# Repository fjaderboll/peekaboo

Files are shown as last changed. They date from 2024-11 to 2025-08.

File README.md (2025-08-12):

# Peek-a-boo
A mobile robot that like to play hide-n-seek with you or just
follow you around.

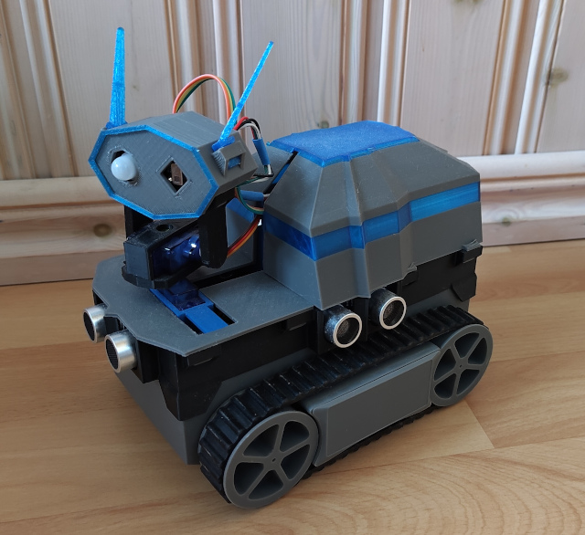
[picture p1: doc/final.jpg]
final Final


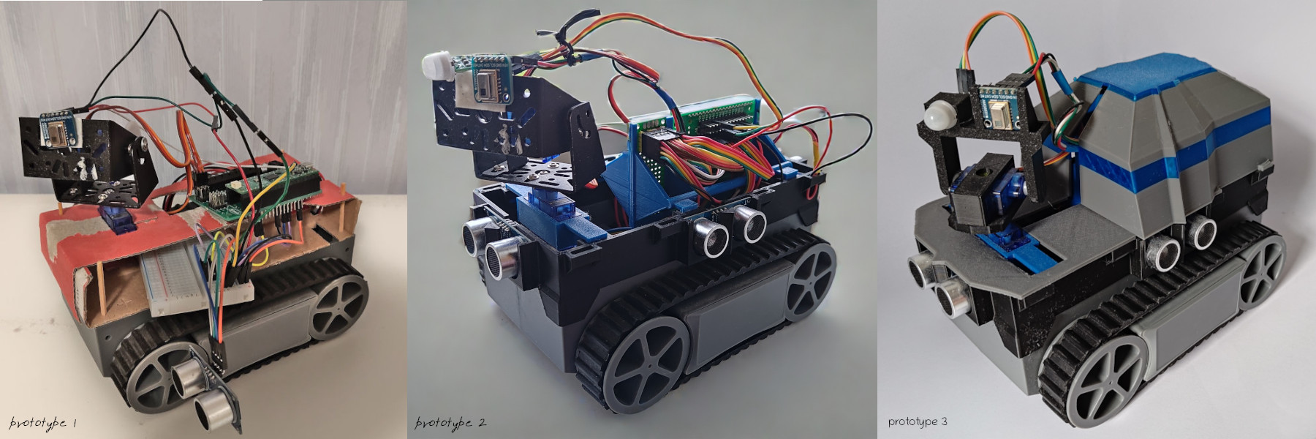
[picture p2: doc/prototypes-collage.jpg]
prototypes Prototypes


More technically, it will use a heat camera to detect humans
and ultrasonic sensors for navigating a flat surface with obstacles.
If left unattended it will go to asleep and awoken by movement.

Watch it in action on [YouTube](https://www.youtube.com/watch?v=vqpeKBAsQWM).

## Hardware parts
* Crawler: wheel base with motors and battery pack
* Microcontroller: [Raspberry Pi Pico H](https://www.raspberrypi.com/documentation/microcontrollers/pico-series.html#pico-1-family) ([pinout](https://www.raspberrypi.com/documentation/microcontrollers/images/pico-pinout.svg))
* Heat camera: AMG8833 ([library](https://github.com/peterhinch/micropython-amg88xx))
* Motor/servo shield: [Kitronik Robotics Board](https://github.com/KitronikLtd/Kitronik-Pico-Robotics-Board-MicroPython) ([pinout](https://kitronik.co.uk/cdn/shop/products/5329_additional-1-kitronik-robotics-board-for-raspberry-pi-pico_800x.jpg))
* Servo motors: 2 x SG90
* Movement detection: PIR [SR505](https://hobbycomponents.com/sensors/1066-sr505-miniature-pir-sensor-module) **\***
* Ultrasonic sensors: 4 x HC-SR04
* Sound: Passive piezo buzzer
* Power switch: Toggle switch
* Body parts: [see more here](body-parts/README.md)

**\*** SR505 needs 5-12V to behave correctly, and the Robotics Board supply only 3.3V for peripherals, so *VIN* connected directly to the battery PIN.

## Software
I use *Thonny* for installing MicroPython and for coding *Visual Studio Code* with extension `MicroPico`.

Either way, upload content in folder `app` into root of the microcontroller. (VSCode command `MicroPico: Upload project to Pico`)

## Limitations and room for improvements
The head will focus on the warmest thing in view, which works pretty well.
However, the "human detection" is very simplistic; if the center of the heat
camera's image has an average temperature above 25 degrees it's a hit.
It's not much you can do with a 8x8 pixel image, but some form of shape
recognition should be possible.

Navigation is pretty much drive forward-ish (where the head points) until too
close to something, then turn away from obstacle, repeat.
The ultrasonic sensors may be good at determine the distance, but it's hard to
tell the angle to the obstacle. And with only four of them, it leaves several
dead angles. Though, some form of obstacle heat map or SLAM might still be
possible.

Also, a bump sensor of some sort would be a plus; the ultrasonic sensor is
equally bad vertically, so too low or semi-high obstacles may not be seen and
it will endlessly try to continue driving.

## Abandoned paths
I've been intrigued to use AI, and the Pico should be strong enough handle small models.
However, TensorFlow Lite in conjuction with MicroPython posed a too great challenge at the moment.

Also considered using *Pico 2 W* and connect a Bluetooth gamepad for manual driving,
which would have come handy in generating training data for a model. However,
at the moment native Bluetooth support is very limited.

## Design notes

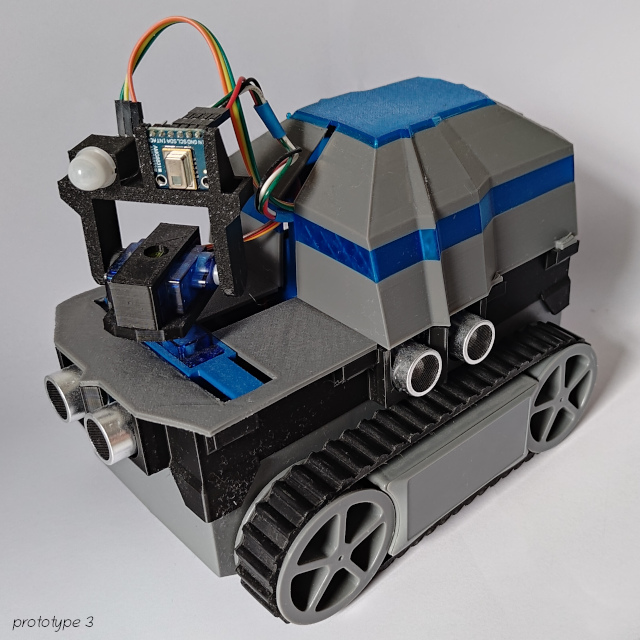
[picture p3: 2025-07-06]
doc/prototype3.jpg

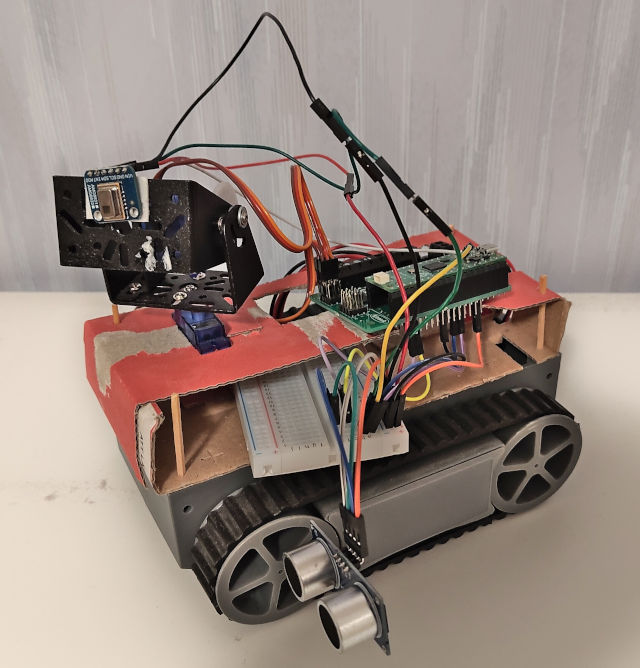
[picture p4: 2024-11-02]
doc/prototype1.jpg

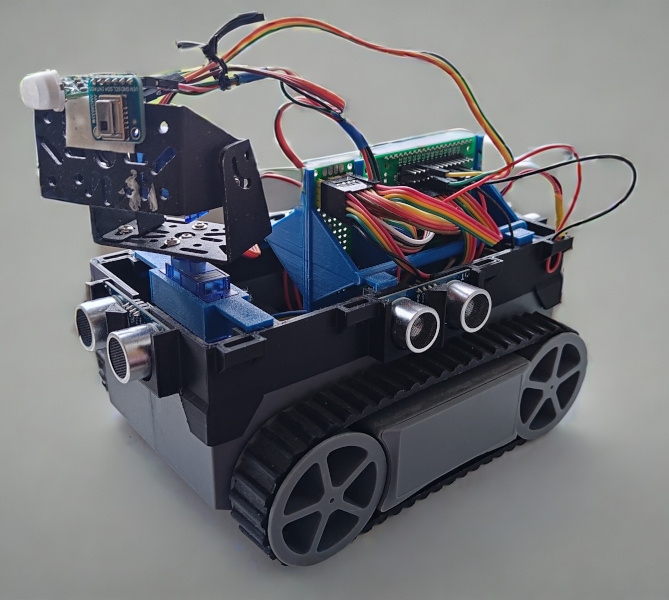
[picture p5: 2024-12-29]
doc/prototype2.jpg

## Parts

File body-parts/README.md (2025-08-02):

# Body parts - 3D-printable
These models are made using OpenSCAD.

## Base / inside

* **Grey** base frame (`base.scad`)
* **Red/blue** snap-on to crawler (`base_clip.scad`)
* **Aqua** ultrasonic holders (`ultrasonic-holder.scad`)
* **Yellow** addon holders (`addon_support.scad`)
* **Orange** addons for servo motor and PCBs (`addon_servo.scad`, `addon_shield.scad`)
* **Green** PCBs just for illustration (`pcb.scad`)

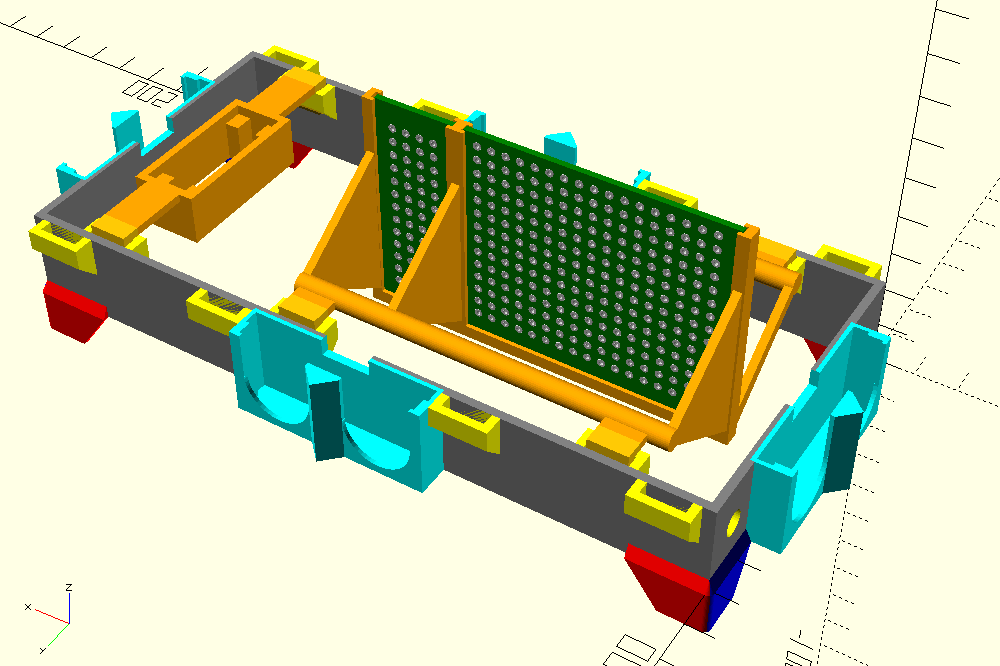
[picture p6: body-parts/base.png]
base Base


## Head
Servo-tilt with sockets for the heat camera and the PIR sensor.
Also addon holders for exterior case.

* **Yellow/blue** tilt/pitch frame with heat camera and PIR mount (`head_tilt.scad`)
* **Orange/pink** base/yaw holder for frame (`head_base.scad`)

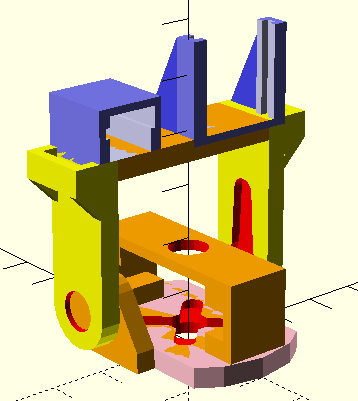
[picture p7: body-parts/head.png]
head Head


## Chassi / outside
Will go into the outer addon holders.

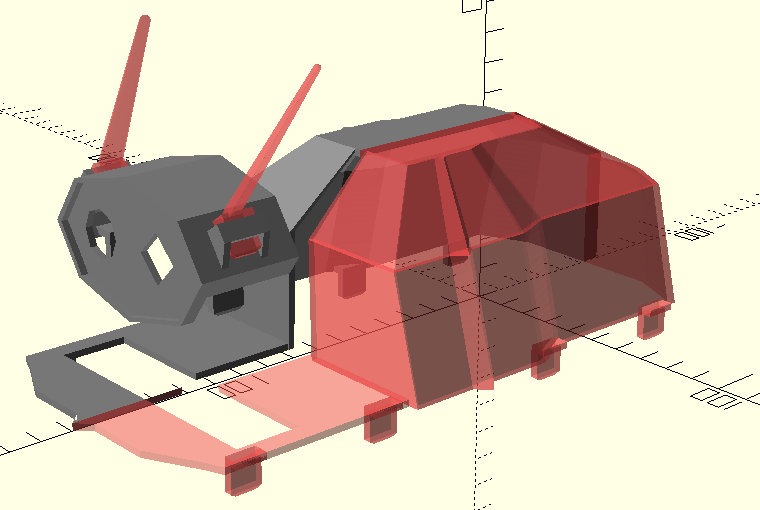
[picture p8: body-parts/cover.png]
cover Cover


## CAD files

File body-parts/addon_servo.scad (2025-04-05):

use <addon_support.scad>

bw = 80;  // base width
wt = 2;   // wall thickness

sw = 12;  // servo width
sl = 23;  // servo length

hl = 32.8; // servo holder length
ht = 2.5;  // servo holder thickness
cw = 4.8;  // cord width
co = 10;   // cord offset from holder

m = 0.20; // margin

module servo_box() {
    color("orange") translate([0, 0, -(ht+co)/2]) cube([sw+2*m+2*wt, hl+2*m+2*wt, ht+co], center=true);
}

module servo_holder() {
    difference() {
        servo_box();
    
        color("orange")  {
            // top hole for holder
            translate([0, 0, 0]) cube([sw+2*m, hl+2*m, 2*ht], center=true);
            // bottom hole for body
            translate([0, 0, -co]) cube([sw+2*m, sl+2*m, 2*co], center=true);
            // cord hole
            translate([0, 0, -co]) cube([cw+2*m, hl+2*m, 2*co], center=true);
        }
    }
}

module addon_servo() {
    w = bw-2*wt;
    
    difference() {
        translate([0, -w/2, -wt]) addon_bar(w);
        translate([0, 0, 0.1]) servo_box();
    }
    servo_holder();
}

addon_servo();

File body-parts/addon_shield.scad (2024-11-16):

bw = 80;   // base width
wt = 2;    // wall thickness

m = 0.30;  // margin
pt = 1.5;  // PCB thickness
ht = 1.0;  // holder thickness

sw = 64.4; // shield width
sh = 53.5; // shield height
aw = 20;   // addon card width
ah = 80;   // addon card height

use <addon_support.scad>

module addon_shield() {
    w = bw-2*wt;
    
    module clips_oneside() {
        translate([0, -w/2, -wt]) addon_bar(width=15, single_clip=true);
        translate([75, -w/2, -wt]) addon_bar(width=15, single_clip=true);
        color("orange") translate([-9.5, -w/2+10, 1-wt]) rotate(90, [0, 1, 0], $fn=40) cylinder(h=90.5, d=5);
    }
    module clips() {
        clips_oneside();
        mirror([0, 1, 0]) clips_oneside();
    }
    module cards_holder() {
        tw = wt+sw+wt+aw+wt+4*m;
        tt = ht+pt+ht+2*m;
        th = wt+sh+m;
        
        difference() {
            // full size
            translate([0, -tt/2, 0]) cube([tw, tt, th]);
            // shield hole
            x1=wt;
            translate([x1, -(pt+2*m)/2, wt]) cube([sw+2*m, pt+2*m, th]);
            // see-through shield hole
            translate([x1+ht, -tt, wt+ht]) cube([sw+2*m-2*ht, 2*tt, th]);
            translate([x1+ht+2, -(pt+m)/2-tt, -wt]) cube([sw+2*m-2*ht-5-3, tt, th]);
            
            // addon card hole
            x2=x1+wt+sw+3*m;
            translate([x2, -(pt+2*m)/2, wt]) cube([aw+2*m, pt+2*m, th]);
            // see-through addon card hole
            translate([x2+ht, -tt, wt+ht]) cube([aw+2*m-2*ht, 2*tt, th]);
        }
    }
    module foot() {
        s=26;
        translate([0, -28, -1])
        rotate(90, [0, 0, 1])
        rotate(90, [1, 0, 0])
        linear_extrude(height=wt)
        polygon([
            [0, 2.5],
            [s, -17.5],
            [s, -22.5],
            [0, -1]
        ]);
    }
    module triangle() {
        s=29;
        translate([0, -30.5, -1])
        rotate(90, [0, 0, 1])
        rotate(90, [1, 0, 0])
        linear_extrude(height=wt)
        polygon([
            [0, 0],
            [s, s/1.5],
            [s, -s/1.5]
        ]);
    }
    /*module triangle_light() {
        difference() {
            triangle();
            translate([-0.1, 0, 0]) scale([1.1, 0.7, 0.7]) triangle();
        }
    }*/
    module cards_holder_holder() {
        translate([-9.5, 0, 0]) foot();
        translate([57, 0, 0]) triangle();
        translate([79, 0, 0]) triangle();
        
        translate([-9.5, 0, 0]) mirror([0, 1, 0]) triangle();
        translate([57, 0, 0]) mirror([0, 1, 0]) triangle();
        translate([79, 0, 0]) mirror([0, 1, 0]) triangle();
    }
    
    clips();
    color("orange") translate([-10, 0, -22-wt]) cards_holder();
    color("orange") cards_holder_holder();
}

addon_shield();

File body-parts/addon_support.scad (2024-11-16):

iw = 10;  // inner width
it = 3;   // inner thickness
h = 5;    // height
wt = 2;   // wall thickness
m = 0.30; // margin

module addon_holder() {
    module reinforcement() {
        rotate(90, [0, 0, 1])
        rotate(90, [1, 0, 0])
        linear_extrude(height=wt)
        polygon([
            [0, 0],
            [it+wt, 0],
            [0, -h]
        ]);
    }
    
    color("yellow") translate([-wt-iw/2, 0, -h]) {
        difference() {
            cube([iw+2*wt, it+wt, h]);
            translate([wt, -1, -1]) cube([iw, it+1, h+2]);
        }
        reinforcement();
        translate([iw+wt, 0, 0]) reinforcement();
    }
}

module addon_clip(bar_length=0) {
    ch = 1.5*h;
    
    color("#fcc705") {
        translate([-(iw-2*m)/2, m, -ch])
        cube([iw-2*m, it-2*m, ch]);
        
        translate([-(iw-2*m)/2, m, 0])
        cube([iw-2*m, it+wt-m, wt]);
    
        translate([0, (it-2*m)/2+m, -ch-1])
        resize([iw-2*m, it-2*m, 1])
        rotate(45, [0, 0, 1])
        cylinder(h=1, r1=it/3, r2=it/2, $fn=4);
    }
}

module addon_bar(width, single_clip=false) {
    addon_clip();
    if(!single_clip) {
        translate([0, width, 0]) mirror([0, 1, 0]) addon_clip();
    }
    
    color("orange")
    translate([-(iw-2*m)/2, it+wt, 0])
    cube([iw-2*m, width-2*(it+wt), wt]);
}

addon_holder();
//addon_bar(width=15, single_clip=true);
addon_bar(width=20);

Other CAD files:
body-parts/base.scad
body-parts/addon_bar_test.scad
body-parts/base_clip.scad
body-parts/cover_back.scad
body-parts/cover_front.scad
body-parts/head_antenna.scad
body-parts/head_base.scad
body-parts/head_face.scad
body-parts/head_tilt.scad
body-parts/mount_heat_camera.scad
body-parts/mount_pir.scad
body-parts/pcb.scad
body-parts/ultrasonic-holder.scad

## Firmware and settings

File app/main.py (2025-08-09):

import gc
import utime
from machine import Pin, SoftI2C

import PicoRobotics
from buzzer import Buzzer
from buzzer_sounds import Sounds
from ultrasonic import Ultrasonic

from head import Head
from body import Body

print('Starting...')

# === init variables ===
pirPin = Pin(19, Pin.IN)
ledPin = Pin("LED", Pin.OUT)

board = PicoRobotics.KitronikPicoRobotics() # uses i2c1
buzzer = Buzzer(18)
sounds = Sounds(buzzer)
i2c0 = SoftI2C(scl=Pin(17), sda=Pin(16), freq=100_000)
utime.sleep(1)

sensor_front = Ultrasonic(11, 15, 'Front')
sensor_left  = Ultrasonic(10, 14, 'Left')
sensor_right = Ultrasonic(7, 13, 'Right')
sensor_back  = Ultrasonic(6, 12, 'Back')

head = Head(board, i2c0, servo_yaw=7, servo_pitch=8)
body = Body(board, head, sensor_front, sensor_left, sensor_right, sensor_back)

# === end init variables ===

def mem():
  gc.collect()
  free = gc.mem_free()
  alloc = gc.mem_alloc()
  total = free + alloc
  print(f'Memory used: {alloc/total*100:.1f}%')

def pir_irq(pin):
    global sleep_mode

    if pin.value():
        print('PIR detected motion')
        sleep_mode = False
    else:
        print('PIR motion stopped')
    
    ledPin.value(pin.value())

def start():
    global sleep_mode

    print('Started')
    sounds.play_startup()

    start_time = utime.ticks_ms()
    start_hold = True
    last_found_time = start_time
    last_found_someone = False
    last_print_time = 0
    sleep_mode = False

    while True:
        # stay still initially
        if start_hold:
            start_hold = (utime.ticks_diff(utime.ticks_ms(), start_time) < 7000)
            if not start_hold:
                sounds.play_startup_end()

        # move stuff
        head.update()
        body.update(start_hold)

        # did we find someone?
        if head.has_found_someone():
            if not last_found_someone:
                print('Found someone')
                sounds.play_found_someone()
                last_found_someone = True
                last_found_time = utime.ticks_ms()
        else:
            if last_found_someone:
                print('Lost someone')
                sounds.play_lost_someone()
                last_found_someone = False
            
            # go to sleep after if no one found in a while
            if utime.ticks_diff(utime.ticks_ms(), last_found_time) > 60000:
                print('Entering sleep mode')
                body.stop_motors()
                head.sleep_position()
                sleep_mode = True
                sounds.play_sleep()
                break

        # debug print state
        if utime.ticks_diff(utime.ticks_ms(), last_print_time) > 1000:
            #head.print_state(print_camera=False)
            body.print_state()
            last_print_time = utime.ticks_ms()
        
        # idle a little
        utime.sleep_ms(10)

# === main ===
sleep_mode = False
pirPin.irq(trigger=Pin.IRQ_RISING | Pin.IRQ_FALLING, handler=pir_irq)

try:
    while True:
        if not sleep_mode:
            start()
        utime.sleep_ms(500)
except KeyboardInterrupt:
    print('KeyboardInterrupt')
finally:
    print('Shutting down')
    body.stop_motors()
    buzzer.silent()

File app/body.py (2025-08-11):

import utime

from PicoRobotics import KitronikPicoRobotics
from ultrasonic import Ultrasonic
from head import Head

class Body:
    DIRECTION_FORWARD: str = 'r'  # switched reverse and forward to match reality
    DIRECTION_BACKWARD: str = 'f'
    MOTOR_LEFT: int = 1
    MOTOR_RIGHT: int = 2
    SPEED_MIN: int = 25  # below this the motor doesn't move
    SPEED_MAX: int = 100

    def __init__(self, board: KitronikPicoRobotics, head: Head, sensor_front: Ultrasonic, sensor_left: Ultrasonic, sensor_right: Ultrasonic, sensor_back: Ultrasonic):
        self.board = board
        self.head = head
        self.sensor_front = sensor_front
        self.sensor_left  = sensor_left
        self.sensor_right = sensor_right
        self.sensor_back  = sensor_back
        
        self.sensors = [sensor_front, sensor_left, sensor_right, sensor_back]
        self.proximity_threshold = 5
        self.sensor_update_interval = 250
        self.last_update_time = 0

        self.angle = 0        # range: -180 to +180
        self.speed = 0        # range:    0 to +100
        self.last_speed = -1
        self.last_angle = -1
        self.speed_slowdown = 100

        self.mode_text = 'init'

    def get_distances(self):
        return [sensor.get_last_distance() for sensor in self.sensors]

    def print_state(self):
        for sensor in self.sensors:
            print(f'l{sensor.get_name()}: {sensor.get_last_distance():.1f} cm', end=' ')
        print(f'speed: {self.speed}, angle: {self.angle}, head_angle: {self.head.get_direction_angle()}, mode: {self.mode_text}')

        #for sensor in self.sensors:
        #    print(f'c{sensor.get_name()}: {sensor.get_calibrated_distance():.1f} cm', end=' ')
        #print()

    def read_sensors(self):
        for i, sensor in enumerate(self.sensors):
            sensor.measure_distance()
    
    def get_safe_speed(self, speed):
        return int(max(self.SPEED_MIN, min(speed, self.SPEED_MAX)))

    def calculate_movement(self, stand_still: bool = False):
        if stand_still:
            self.mode_text = 'stand still'
            self.speed = 0
            self.speed_slowdown = 100
            self.angle = 0
        elif self.head.has_found_someone():
            self.mode_text = 'found someone'
            self.speed = 0
            self.speed_slowdown = 100
            self.angle = self.head.get_direction_angle()
            if abs(self.angle) < 30:
                self.angle = 0
        else:
            distance_front = self.sensor_front.get_calibrated_distance()
            distance_left  = self.sensor_left.get_calibrated_distance()
            distance_right = self.sensor_right.get_calibrated_distance()
            distance_back  = self.sensor_back.get_calibrated_distance()
            head_angle = self.head.get_direction_angle()

            if distance_front < 10 and distance_back > 10: # move backward (at an angle)
                self.mode_text = 'back'
                self.speed = 1 # slowest possible
                self.speed_slowdown = 100
                self.angle = (-150 if distance_left < distance_right else 150)
            elif distance_front < 20: # turn on the spot
                self.mode_text = 'turn'
                self.speed = 0
                self.speed_slowdown = max(50, self.speed_slowdown + 5)
                self.angle = 20 * (1 if head_angle > 0 else -1)
            else: # move forward against the head angle but stay away from obstacles
                self.mode_text = 'forward'
                df = min(1, distance_front / 100)
                dl = min(1, distance_left / 100)
                dr = min(1, distance_right / 100)
                self.speed = self.get_safe_speed(df * 50 + dl * 25 + dr * 25)
                self.speed_slowdown = max(0, self.speed_slowdown - 5)
                self.angle = head_angle * 1.0 - dl * 30 + dr * 30
        
        self.speed = self.speed if self.speed == 0 else self.get_safe_speed(self.speed - self.speed_slowdown)
        self.angle = int(self.angle)

    def update_motors(self):
        if self.last_angle == self.angle and self.last_speed == self.speed:
            return

        if self.speed == 0 and abs(self.angle) <= 10:
            self.stop_motors()
        elif self.speed == 0:
            angle_speed = self.get_safe_speed(abs(self.angle))
            self.board.motorOn(self.MOTOR_LEFT,  self.DIRECTION_BACKWARD if self.angle < 0 else self.DIRECTION_FORWARD, angle_speed)
            self.board.motorOn(self.MOTOR_RIGHT, self.DIRECTION_BACKWARD if self.angle > 0 else self.DIRECTION_FORWARD, angle_speed)
        else:
            direction = self.DIRECTION_FORWARD if abs(self.angle) <= 90 else self.DIRECTION_BACKWARD
            angle_offset_speed = abs(self.angle) if abs(self.angle) <= 90 else 180 - abs(self.angle)
            speed_left = self.get_safe_speed(self.speed - (0 if self.angle >= 0 else angle_offset_speed))
            speed_right = self.get_safe_speed(self.speed - (0 if self.angle <= 0 else angle_offset_speed))

            if speed_left == self.SPEED_MIN and speed_right == self.SPEED_MIN and self.angle not in [0, 180]:
                if self.angle < 0:
                    speed_left = 0
                else:
                    speed_right = 0

            self.board.motorOn(self.MOTOR_LEFT, direction, speed_left)
            self.board.motorOn(self.MOTOR_RIGHT, direction, speed_right)

        self.last_speed = self.speed
        self.last_angle = self.angle
    
    def stop_motors(self):
        self.board.motorOff(self.MOTOR_LEFT)
        self.board.motorOff(self.MOTOR_RIGHT)

    def update(self, stand_still: bool = False):
        if utime.ticks_diff(utime.ticks_ms(), self.last_update_time) > self.sensor_update_interval:
            self.read_sensors()
            self.calculate_movement(stand_still)
            self.update_motors()
            self.last_update_time = utime.ticks_ms()
            return True
        return False
        

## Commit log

2024-10-04 Improved heat rendering
2024-10-04 Motor shield from Kitronik
2024-11-02 Added ultrasonic test
2024-11-03 First draft of the structure to 3D print, using OpenSCAD
    [base.scad, ultrasonic-holder.scad]
2024-11-03 Ultrasonic holder adjustments
    [ultrasonic-holder.scad]
2024-11-12 Updated base designs
    [base.scad, base_clip.scad, ultrasonic-holder.scad]
2024-11-12 Case base addon holders
    [addon_holder.scad, base.scad, base_clip.scad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]
2024-11-14 Case addon continued
    [addon_bar_test.scad, addon_holder.scad, addon_support.scad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]
2024-11-14 Addon for the servo
    [addon_bar_servo.scad, base.scad]
2024-11-16 Base structure complete
    [addon_bar_servo.scad, addon_servo.scad, addon_shield.scad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]
2024-11-17 Base case tweaks
    [base.scad, ultrasonic-holder.scad]
2024-11-17 Case preview added
    [base.scad, pcb.scad]
2025-03-28 LED now works
2025-04-05 Pan-tilt parts for the head
    [addon_servo.scad, head_base.scad, head_tilt.scad]
2025-04-06 Head servo part tweaks
    [head_base.scad, head_tilt.scad]
2025-04-06 Folder rename and doc tweaks
    [addon_bar_test.scad, addon_servo.scad, addon_shield.scad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]
2025-04-14 Head mount tweaks
    [head_base.scad, head_tilt.scad, mount_heat_camera.scad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]
2025-05-27 Cover parts
    [base.scad, cover_back.scad, cover_front.scad]
2025-07-06 Somewhat avoiding things now
    [body.py, head.py, main.py]
2025-07-06 Introduced speed slowdown in tight spots
    [body.py]
2025-07-06 Updated prototype images
2025-08-02 Head skull
    [head_face.scad, head_tilt.scad]
2025-08-02 Head antenna
    [head_antenna.scad]
2025-08-02 Body part doc update
    [base.scad]
2025-08-09 Movement fixes and tweaks
    [body.py, head.py, head_tracking.py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]
